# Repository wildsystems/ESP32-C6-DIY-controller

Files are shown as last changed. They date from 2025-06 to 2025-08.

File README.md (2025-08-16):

# ESP32-C6 Sensor Controller

## 📊 Description
This project is a basic controller built around the ESP32-C6-MINI-1, designed for monitoring and managing temperature, humidity, flow, and PWM-based sensors/actuators. It supports direct connection for four NTC thermistors, one DHT21 sensor, a 1-Wire bus with DS18B20, one pulse input for a Hall effect flow sensor, one PWM input, one PWM output, and two relay outputs. Additionally, it includes a USB-C connector for power and communication, supporting USB-CDC (virtual serial) and JTAG debugging.

---

## 🔧 Key Features

| Component | Description |
|---|---|
| 🌡️ 4x NTC Inputs | Analog reading via voltage divider with fixed resistor |
| 🔋 1x DHT21 (AM2301) | Temperature and humidity sensor |
| ❄️ 1x DS18B20 (1-Wire) | Bus for Dallas 1-Wire temperature sensors |
| 🚿 1x Flow Sensor (HALL) | Pulse-based flow measurement |
| 🎛️ 1x PWM Input | Frequency or duty-cycle based input |
| 🔉 1x PWM Output | PWM signal output for motor/valve control |
| ⚙️ 2x Relay Outputs | Load control (e.g. pump, valve) |
| 🔌 1x USB-C Connector | Power input, USB-CDC serial, and JTAG debug support |

---

## ⚙️ Pin Assignment (ESP32-C6-MINI-1 Safe GPIOs)

| Function | GPIO Pin | Notes |
|---|---|---|
| NTC1 (analog in) | GPIO1 | ADC1 channel |
| NTC2 | GPIO3 | ADC1 channel |
| NTC3 | GPIO4 | ADC1 channel |
| NTC4 | GPIO5 | ADC1 channel |
| DHT21 / DS18B20 | GPIO6 | 4.7k pull-up to 3.3V |
| Flow Sensor (input) | GPIO7 | Interrupt on rising edge |
| PWM Input | GPIO14 | Timer capture capable |
| PWM Output | GPIO15 | LEDC or MCPWM output |
| Relay 1 (output) | GPIO18 | Load control |
| Relay 2 | GPIO19 | Load control |
| USB D+ | GPIO13 | Native USB data+ (shared with UART RX) |
| USB D− | GPIO12 | Native USB data− |
---

## 📝 Notes

- All GPIOs used are considered safe for ESP32-C6-MINI-1 boot operation.
- NTC sensors are read via the internal ADC1.
- DHT21 requires at least a 2-second interval between readings.
- DS18B20 supports multiple sensors on a single 1-Wire bus.
- PWM input can be measured using capture/timer functionality.
- PWM output can be generated via LEDC or MCPWM peripheral.
- Relay outputs can be connected to opto-isolated relay modules.
- USB-C port supports 5V input and USB communication (CDC, JTAG).

---

## 🚀 Applications

- Fermentation controller
- Room temperature and humidity monitoring
- Smart irrigation systems
- General home automation
- Fan or valve modulation via PWM
- USB-connected data acquisition

---

## License

This hardware project is licensed under the **CERN-OHL-P v2** (Permissive).
- You may use, modify, and distribute the design files.
- You are free to create derivative works and even release them under a closed license.
- No warranty is provided.

Full text of the license can be found in the [LICENSE](./LICENSE) file.

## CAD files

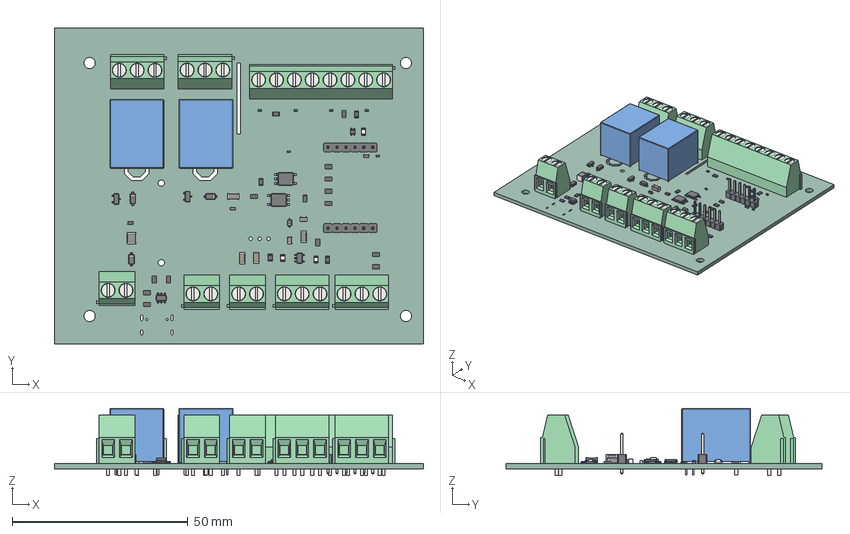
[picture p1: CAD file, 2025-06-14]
hardware/case/watermeter.step
105.0 x 90.0 x 19.1 mm
TSOT-23-5
R_0805_2012Metric x 19
C_0805_2012Metric x 2
Relay_SPDT_SANYOU_SRD_Series_Form_C x 2
SOT-23 x 2
D_SOD-123 x 3
TerminalBlock_Phoenix_MKDS-1,5-3-5.08_1x03_P5.08mm_Horizontal x 4
L_1206_3216Metric
C_1206_3216Metric x 3
D_0805_2012Metric
C_0402_1005Metric x 6
LED_0805_2012Metric x 3
PinHeader_1x06_P2.54mm_Vertical x 2
SO-5_4.4x3.6mm_P1.27mm x 2
L_1210_3225Metric
D_0603_1608Metric
C_0603_1608Metric
SOT-23-6
L_0603_1608Metric
TerminalBlock_Phoenix_MKDS-1,5-8-5.08_1x08_P5.08mm_Horizontal
TerminalBlock_Phoenix_MKDS-1,5-2-5.08_1x02_P5.08mm_Horizontal x 3
D_SOD-323
watermeter_PCB

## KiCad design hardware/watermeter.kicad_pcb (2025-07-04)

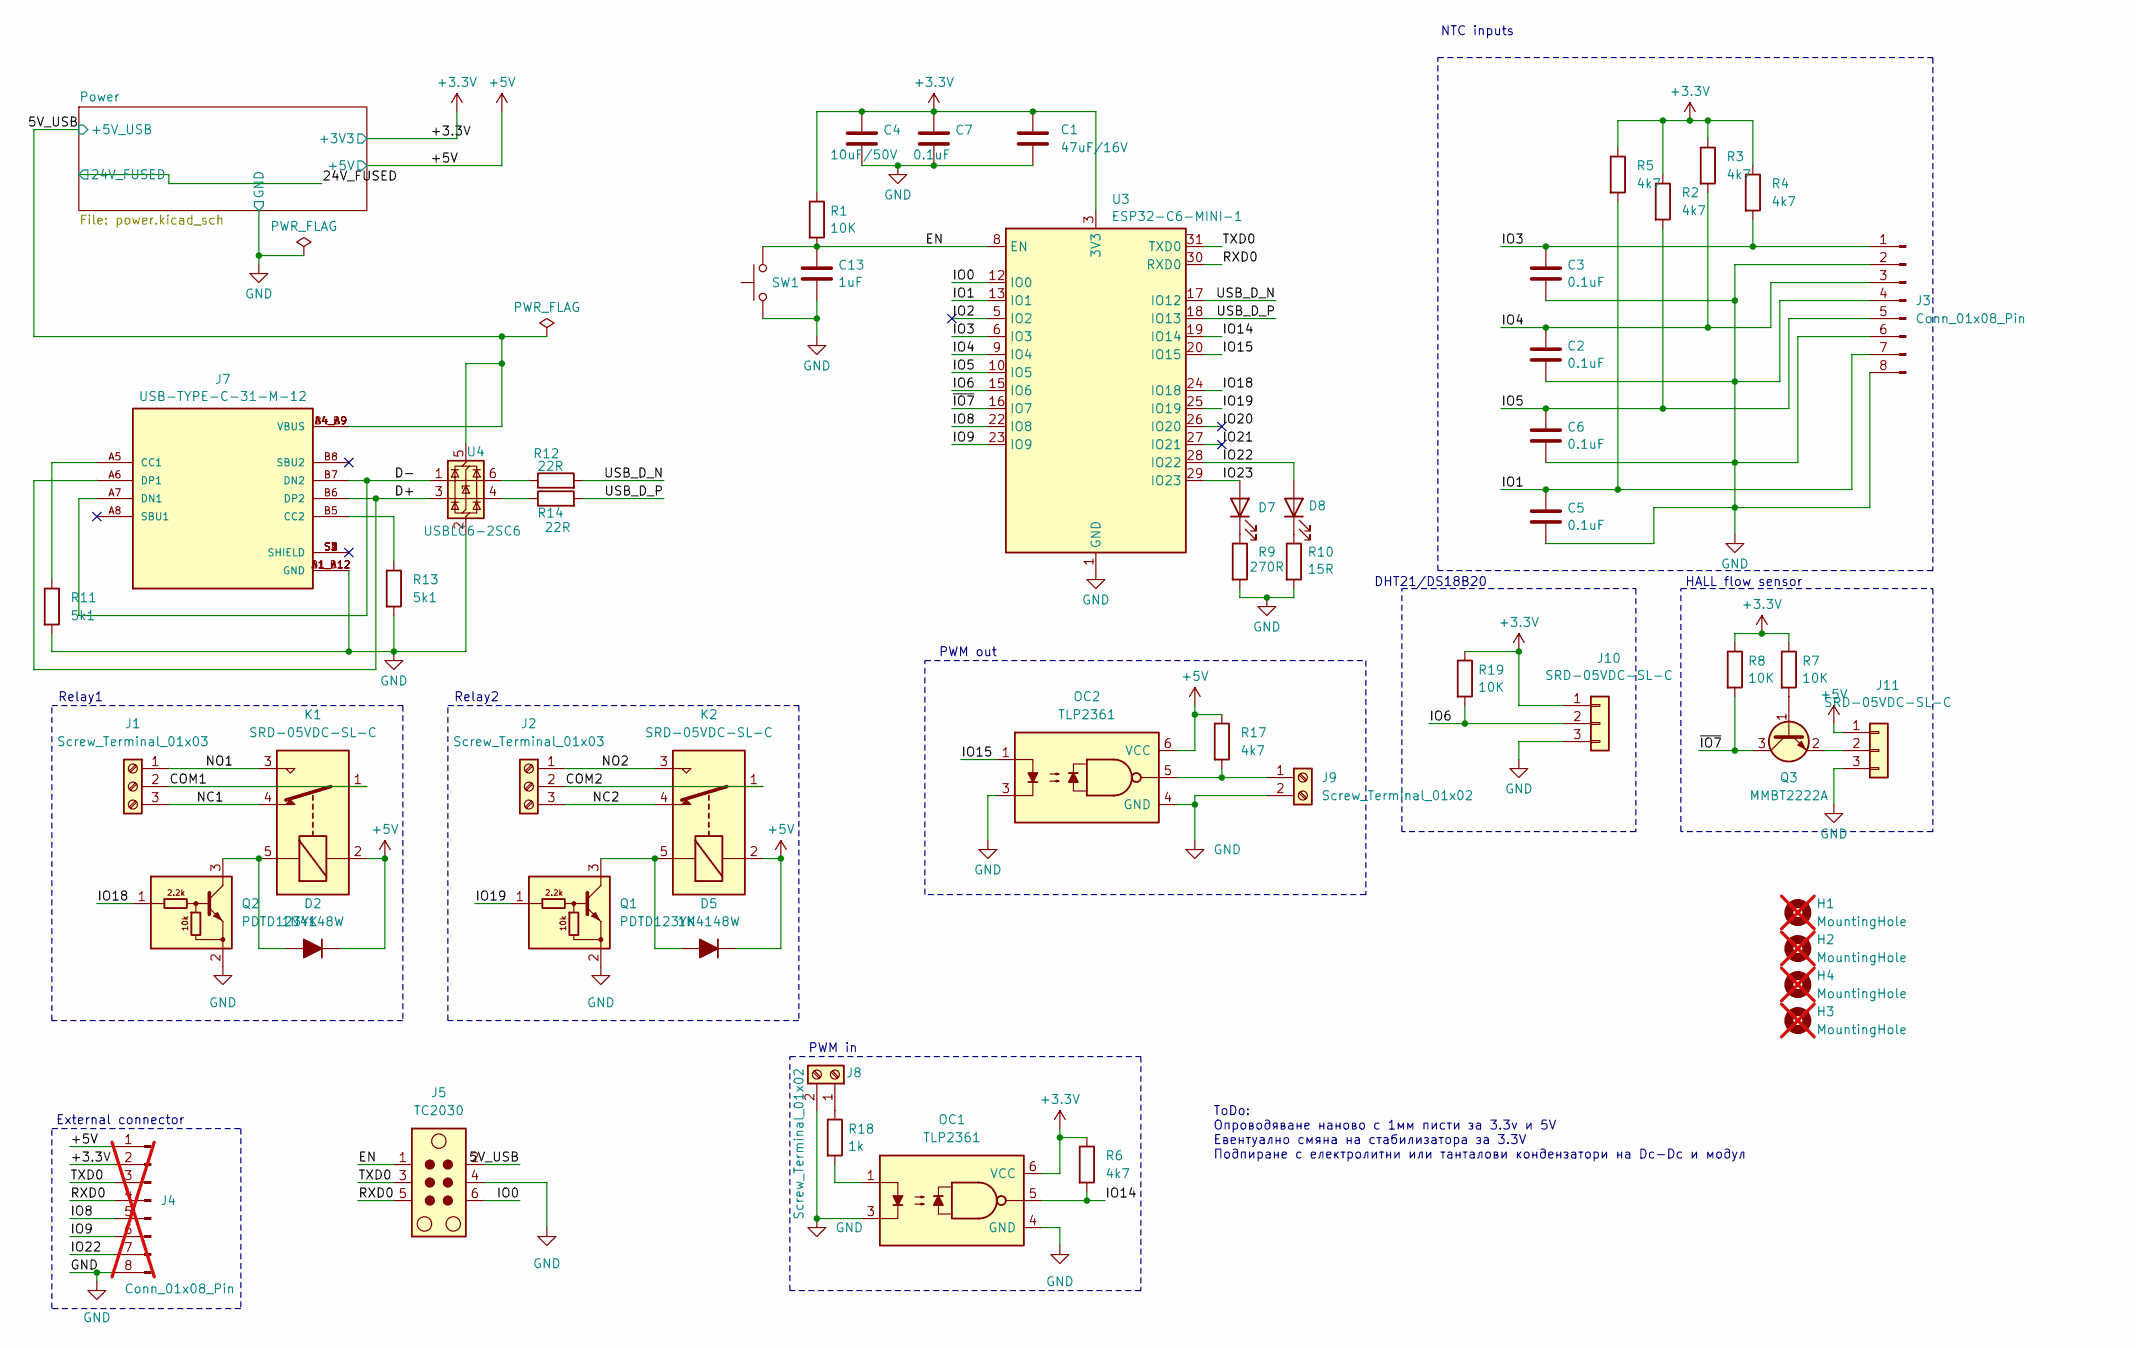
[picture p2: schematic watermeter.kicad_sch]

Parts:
C1: 47uF/16V; C_1206_3216Metric; LCSC Part # C96123
C2, C3, C5, C6, C7: 0.1uF; C_1206_3216Metric; LCSC Part # C24497
C4: 10uF/50V; C_1206_3216Metric; LCSC Part # C13585
C13: 1uF; C_0402_1005Metric; LCSC Part # C14445
D2, D5: 1N4148W; D_SOD-323_HandSoldering; LCSC Part # C2128
D7: KT-0805G; LED_0805_2012Metric; LCSC Part # C2297
D8: KT-0805B; D_0805_2012Metric; LCSC Part # C2293
H1, H2, H3, H4: MountingHole; MountingHole_3.2mm_M3_ISO7380; not fitted
J1, J2: Screw_Terminal_01x03; TerminalBlock_Phoenix_MKDS-1,5-3-5.08_1x03_P5.08mm_Horizont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; LCSC Part # C2915640
J3: Conn_01x08_Pin; TerminalBlock_Phoenix_MKDS-1,5-8-5.08_1x08_P5.08mm_Horizont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; LCSC Part # C5143711
J4: Conn_01x08_Pin; PinHeader_1x08_P2.54mm_Vertical; not fitted
J5: TC2030; Tag-Connect_TC2030-IDC-NL_2x03_P1.27mm_Vertical
J7: USB-TYPE-C-31-M-12; USB-HRO_TYPE-C-31-M-12; LCSC Part # C165948
J8, J9: Screw_Terminal_01x02; TerminalBlock_Phoenix_MKDS-1,5-2-5.08_1x02_P5.08mm_Horizont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; LCSC Part # C2915639
J10, J11: SRD-05VDC-SL-C; TerminalBlock_Phoenix_MKDS-1,5-3-5.08_1x03_P5.08mm_Horizont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; LCSC Part # C2915640
K1, K2: SRD-05VDC-SL-C; Relay_SPDT_SANYOU_SRD_Series_Form_C; LCSC Part # C35449
OC1, OC2: TLP2361; SO-5_4.4x3.6mm_P1.27mm; LCSC Part # C107626
Q1, Q2: PDTD123YK; SC-59; LCSC Part # C295450
Q3: MMBT2222A; SOT-23
R1, R7, R8, R19: 10K; R_0805_2012Metric; LCSC Part # C17414
R2, R3, R4, R5, R6, R17: 4k7; R_0805_2012Metric; LCSC Part # C17673
R9: 270R; LED_0603; LCSC Part # C22966
R10: 15R; R_0805_2012Metric; LCSC Part # C17480
R11, R13: 5k1; R_0805_2012Metric; LCSC Part # C27834
R12, R14: 22R; R_0805_2012Metric; LCSC Part # C17561
R18: 1k; R_0805_2012Metric; LCSC Part # C17513
SW1: Reboot; SW-SMD_4P-L5.1-W5.1-P3.70-LS6.5-TL-2; LCSC Part # C318884
U3: ESP32-C6-MINI-1; LCSC Part # C5736265
U4: USBLC6-2SC6; SOT-23-6; LCSC Part # C7519

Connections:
+3.3V: C1.1, C4.1, C7.1, J4.2, J10.1, OC1.6 (VCC), R1.1, R2.1, R3.1, R4.1, R5.1, R6.1, R7.1, R8.1, R19.1, U3.3 (3V3); also elsewhere on the board
+5V: D2.1 (K), D5.1 (K), J4.1, J11.1, K1.2, K2.2, OC2.6 (VCC), R17.1; also elsewhere on the board
/5V_USB: J5.2, J7.A4_B9 (VBUS), J7.B4_A9 (VBUS), U4.5 (VBUS); also elsewhere on the board
/COM1: J1.2, K1.1
/COM2: J2.2, K2.1
/D+: J7.A6 (DP1), J7.B6 (DP2), U4.3 (I/O2)
/D-: J7.A7 (DN1), J7.B7 (DN2), U4.1 (I/O1)
/EN: C13.1, J5.1, R1.2, SW1.2, U3.8 (EN)
/IO0: J5.6, U3.12 (IO0)
/IO1: C5.1, J3.7, R5.2, U3.13 (IO1)
/IO2: U3.5 (IO2)
/IO3: C3.1, J3.1, R4.2, U3.6 (IO3)
/IO4: C2.1, J3.3, R3.2, U3.9 (IO4)
/IO5: C6.1, J3.5, R2.2, U3.10 (IO5)
/IO6: J10.2, R19.2, U3.15 (IO6)
/IO8: J4.5, U3.22 (IO8)
/IO9: J4.6, U3.23 (IO9)
/IO14: OC1.5, R6.2, U3.19 (IO14)
/IO15: OC2.1, U3.20 (IO15)
/IO18: Q2.1 (B), U3.24 (IO18)
/IO19: Q1.1 (B), U3.25 (IO19)
/IO20: U3.26 (IO20)
/IO21: U3.27 (IO21)
/IO22: D8.2 (A), J4.7, U3.28 (IO22)
/IO23: D7.2 (A), U3.29 (IO23)
/NC1: J1.3, K1.4
/NC2: J2.3, K2.4
/NO1: J1.1, K1.3
/NO2: J2.1, K2.3
/RXD0: J4.4, J5.5, U3.30 (RXD0)
/TXD0: J4.3, J5.3, U3.31 (TXD0)
/USB_D_N: R12.2, U3.17 (IO12)
/USB_D_P: R14.2, U3.18 (IO13)
/~IO7: Q3.3 (C), R8.2, U3.16 (IO7)
GND: C1.2, C2.2, C3.2, C4.2, C5.2, C6.2, C7.2, C13.2, J3.2, J3.4, J3.6, J3.8, J4.8, J5.4, J7.A1_B12 (GND), J7.B1_A12 (GND), J8.2, J9.2, J10.3, J11.3, OC1.3, OC1.4 (GND), OC2.3, OC2.4 (GND), Q1.2 (E), Q2.2 (E), R9.2, R10.2, R11.2, R13.2, SW1.1, U3.1 (GND), U3.2 (GND), U3.11 (GND), U3.14 (GND), U3.36 (GND), U3.37 (GND), U3.38 (GND), U3.39 (GND), U3.40 (GND), U3.41 (GND), U3.42 (GND), U3.43 (GND), U3.44 (GND), U3.45 (GND), U3.46 (GND), U3.47 (GND), U3.48 (GND), U3.49 (GND), U3.50 (GND), U3.51 (GND), U3.52 (GND), U3.53 (GND), U4.2 (GND); also elsewhere on the board
unnamed: D2.2 (A), K1.5, Q2.3 (C)
unnamed: D5.2 (A), K2.5, Q1.3 (C)
unnamed: D7.1 (K), R9.1
unnamed: D8.1 (K), R10.1
unnamed: J7.A5 (CC1), R11.1
unnamed: J7.B5 (CC2), R13.1
unnamed: J8.1, R18.1
unnamed: J9.1, OC2.5, R17.2
unnamed: J11.2, Q3.2 (E)
unnamed: OC1.1, R18.2
unnamed: Q3.1 (B), R7.2
unnamed: R12.1, U4.6 (I/O1)
unnamed: R14.1, U4.4 (I/O2)

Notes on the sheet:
NTC inputs
Relay1
PWM out
HALL flow sensor
External connector
Relay2
PWM in
ToDo: Опроводяване наново с 1мм писти за 3.3v и 5V Евентуално смяна на стабилизатора за 3.3V Подпиране с електролитни или танталови кондензатори на Dc-Dc и модул
DHT21/DS18B20

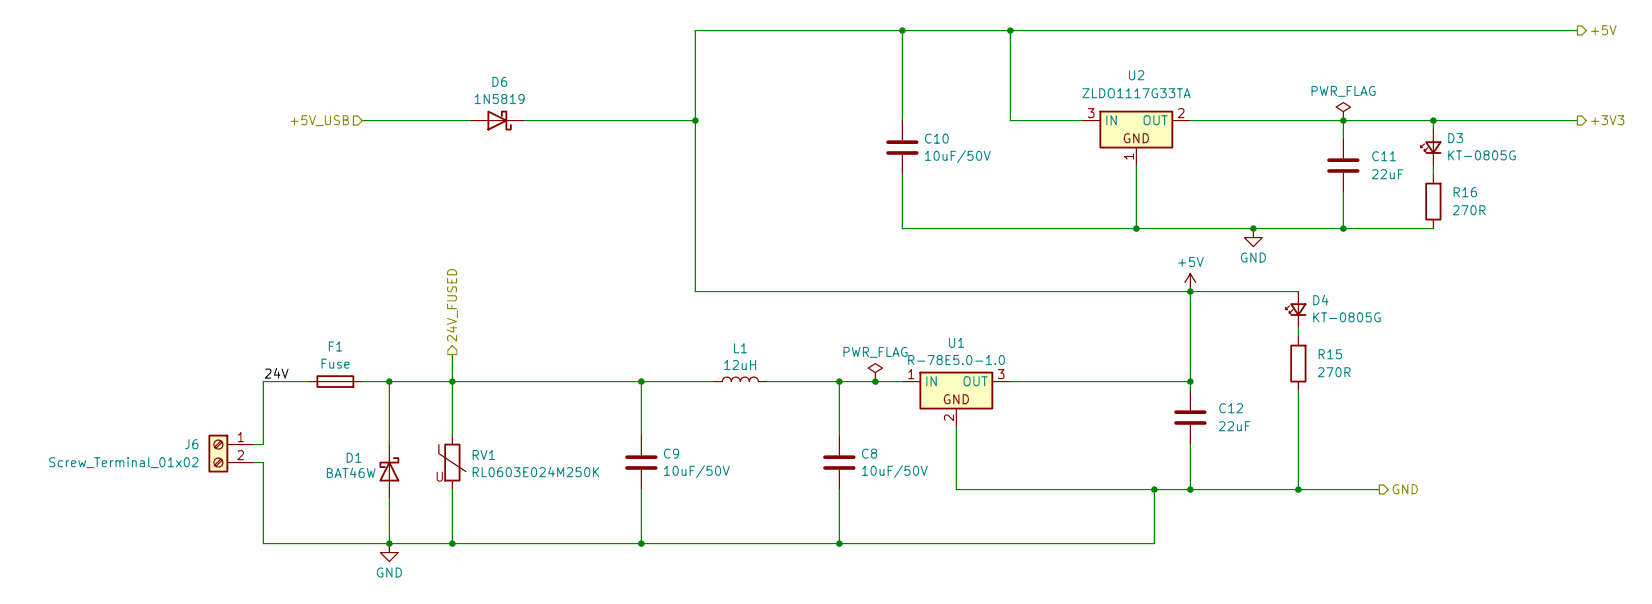
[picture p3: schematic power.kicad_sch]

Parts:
C8, C9, C10: 10uF/50V; C_1206_3216Metric; LCSC Part # C13585
C11, C12: 22uF; C_1206_3216Metric; LCSC Part # C12891
D1: BAT46W; D_SOD-123; LCSC Part # C7420332
D3, D4: KT-0805G; LED_0805_2012Metric; LCSC Part # C2297
D6: 1N5819; D_SOD-323_HandSoldering; LCSC Part # C191023
F1: Fuse; FUSE-TH_L24.4-W9.4-P22.60; LCSC Part # C717030
J6: Screw_Terminal_01x02; TerminalBlock_Phoenix_MKDS-1,5-2-5.08_1x02_P5.08mm_Horizont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; LCSC Part # C2915639
L1: 12uH; IND_ASPI-6045S-120M-T; LCSC Part # C168077
R15, R16: 270R; LED_0603; LCSC Part # C22966
RV1: RL0603E024M250K; D_0603_1608Metric; LCSC Part # C20966
U1: R-78E5.0-1.0; PWRM-TH_K78XX-500R3; LCSC Part # C22371890
U2: ZLDO1117G33TA; SOT-223-3_TabPin2; LCSC Part # C92102

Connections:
+3.3V: C11.1, D3.2 (A), U2.2 (OUT); also elsewhere on the board
+5V: C10.1, C12.1, D4.2 (A), D6.1 (K), U1.3 (OUT), U2.3 (IN); also elsewhere on the board
/5V_USB: D6.2 (A); also elsewhere on the board
/24V_FUSED: C9.1, D1.1 (K), F1.2, L1.1, RV1.1
/Power/24V: F1.1, J6.1
GND: C8.2, C9.2, C10.2, C11.2, C12.2, D1.2 (A), J6.2, R15.1, R16.1, RV1.2, U1.2, U2.1; also elsewhere on the board
unnamed: D3.1 (K), R16.2
unnamed: D4.1 (K), R15.2
unnamed: C8.1, L1.2, U1.1 (IN)

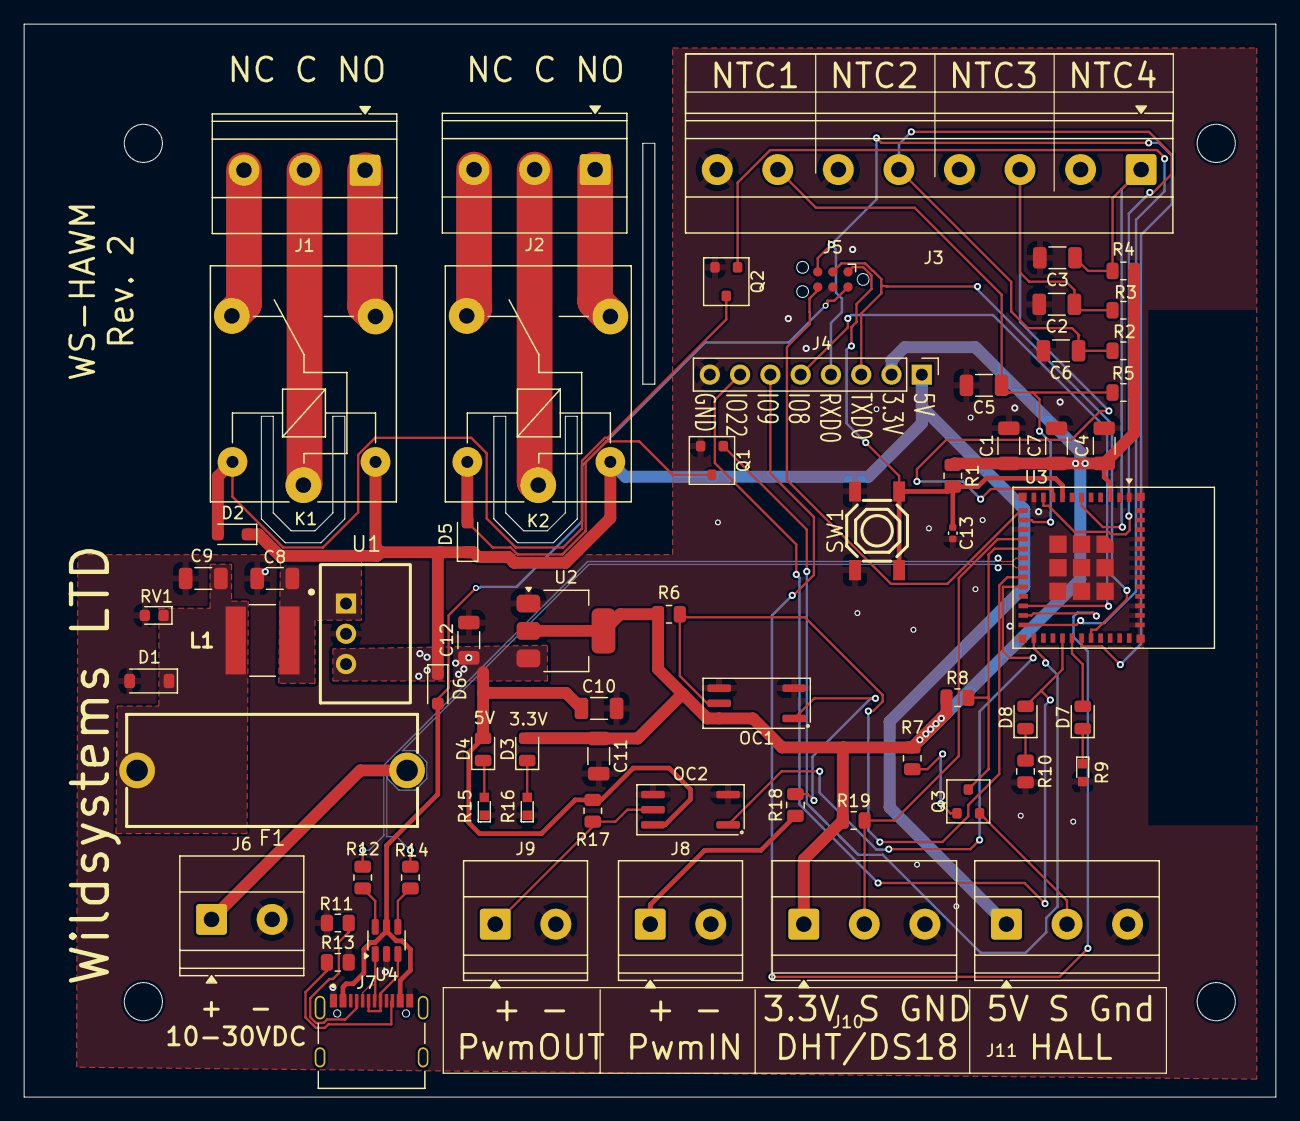
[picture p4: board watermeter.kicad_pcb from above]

Board: 2 copper layers, 105.0 x 90.0 mm, 70 parts (0 on the bottom side), 50 nets.

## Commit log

2025-05-20 Initial import after reorganization
    [power.kicad_sch, watermeter.kicad_pcb, watermeter.kicad_sch]
2025-06-01 Schematics done
    [watermeter.kicad_sch]
2025-06-02 Release hardware design v1.0 for manufacturing
    [power.kicad_sch, watermeter.kicad_pcb, watermeter.kicad_sch]
2025-06-14 fix: unstable power supply
    [power.kicad_sch, watermeter.kicad_pcb, watermeter.kicad_sch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]
2025-06-19 Board V2. fix: power supply fix: NTC noise suppression fix: Q1 and Q2 wrong pin numbers fix: Increased power trice width
    [power.kicad_sch, watermeter.kicad_pcb, watermeter.kicad_sch]
2025-06-19 V2 gerber files
2025-06-27 small fixes
    [watermeter.kicad_pcb]
2025-07-04 Production - V2 Added: TagConnect port for fast firmware upload Fixes: Resistive diider fo hall sensor was replaced with transistor logic Refactoring for whole power supply Minimal track width 0.2mm 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
    [watermeter.kicad_pcb, watermeter.kicad_sch]
